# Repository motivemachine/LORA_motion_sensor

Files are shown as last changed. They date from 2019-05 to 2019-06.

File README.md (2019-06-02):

# LoRa Motion sensor
These are the kicad PCB and software files for the LoRa motion sensor, a wireless proximity alarm using the RCWL-0516 sensor and SX1278 radio. PCB designed in Kicad 5.1. The cache should contain all custom footprints. Handheld receiver design coming soon.

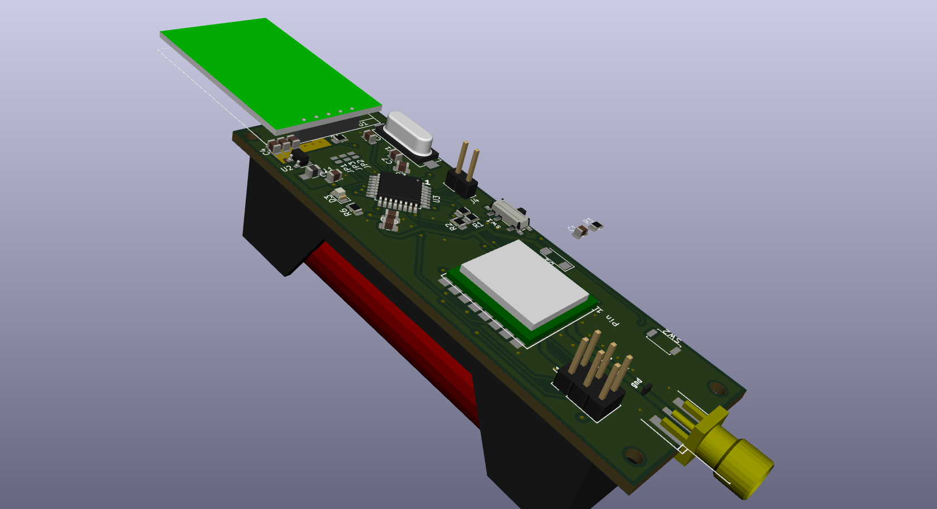
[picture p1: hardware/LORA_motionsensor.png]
sensorrender


### Dependencies
Only dependency is the LoRa radio library by [Sandeep Mistry](https://github.com/sandeepmistry/arduino-LoRa), included in _/firmware/lib/_

### Software usage
Software was created and compiled with PlatformIO, but is usable by any arduino compatible IDE by compiling the program located in _/firmware/src_ as an arduino pro mini 3.3v/8mhz. Upload is done over ISP header. Be careful that programming signals are 3.3 volts, as the LoRa radio is not 5v tolerant.

### Using the device
Simply turn it on and place in an area you'd like to monitor. Choke points are best, such as near a gate, pathway, doorway or vehicle. The sensor works by detecting a phase change in it's 3Ghz oscillator and waking up the processor and radio, then sending the packet 'MOT' via LoRa radio protocol, along with packet and radio ID number.

Sensor range is about 20-30ft out the front and back, and less to the sides. Range seems somewhat dependent on size and speed of the object (dog, man, car, etc.), and whether or not the object is moving across or toward/away from the sensor. Sensor is immune to changes in heat or light, and can 'see' through non-conductive objects. It detects movement of conductive objects, be they people, animal or metal vehicle, and sometimes large amounts of tree leaves. Beware if placing near large leafy things in the wind.

The best documentation on the function and use of this sensor can be found here: (https://github.com/jdesbonnet/RCWL-0516)

The only critical part of placing it is near metal or another sensor. Any metal closer than about 2" to the sensor will cause it to go off constantly, and the sensors will interfere with each other closer than about 10feet(~3meters)

Testing is still ongoing, but the device is mostly feature complete. Sleep modes on the radio and ATmega are getting about two weeks (depending on number of wakeups) on a single 18650 battery.  

### Still todo

- [ ] program CRC and collision detection functions
- [ ] write functions for setting destination and local HEX address with switches or solder jumpers
- [ ] update and test boards with low-battery alert functions
- [x] upload platformio files
- [x] upload .pdf of schematic
- [ ] generate and upload a proper BOM

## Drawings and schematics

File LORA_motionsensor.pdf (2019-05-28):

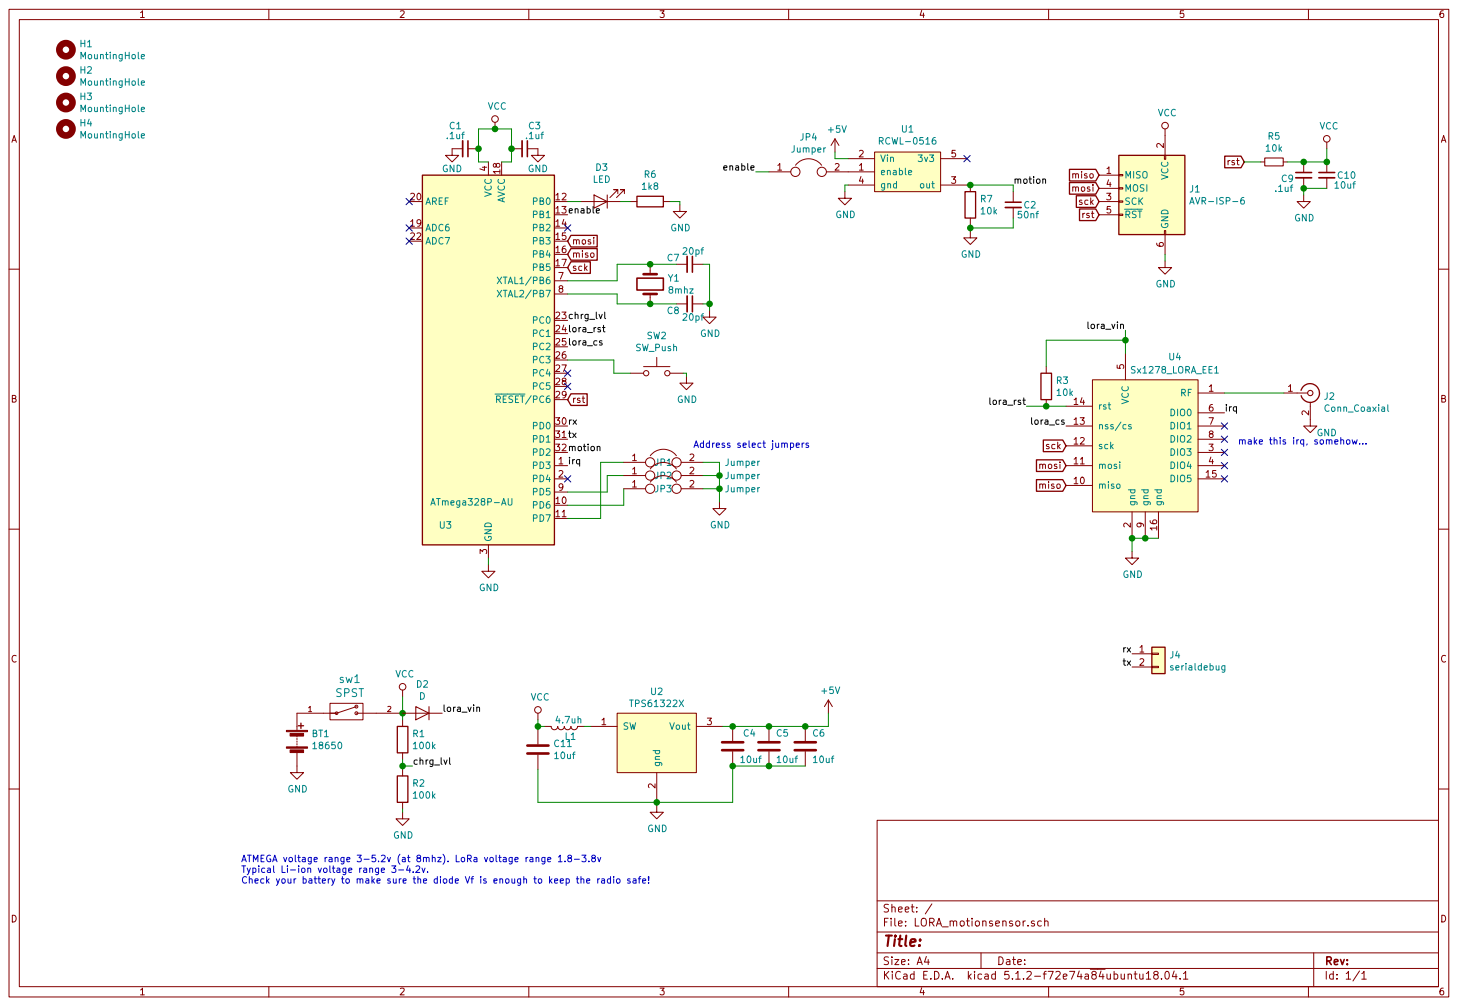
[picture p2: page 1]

2 SCK 3 MOSI 4 RST 5 GND

J2Conn_Coaxial GND miso mosi sck

make this irq, somehow... motion C11

ATMEGA voltage range 3-5.2v (at 8mhz). LoRa voltage range 1.8-3.8v
Typical Li-ion voltage range 3-4.2v.
Check your battery to make sure the diode Vf is enough to keep the radio safe!

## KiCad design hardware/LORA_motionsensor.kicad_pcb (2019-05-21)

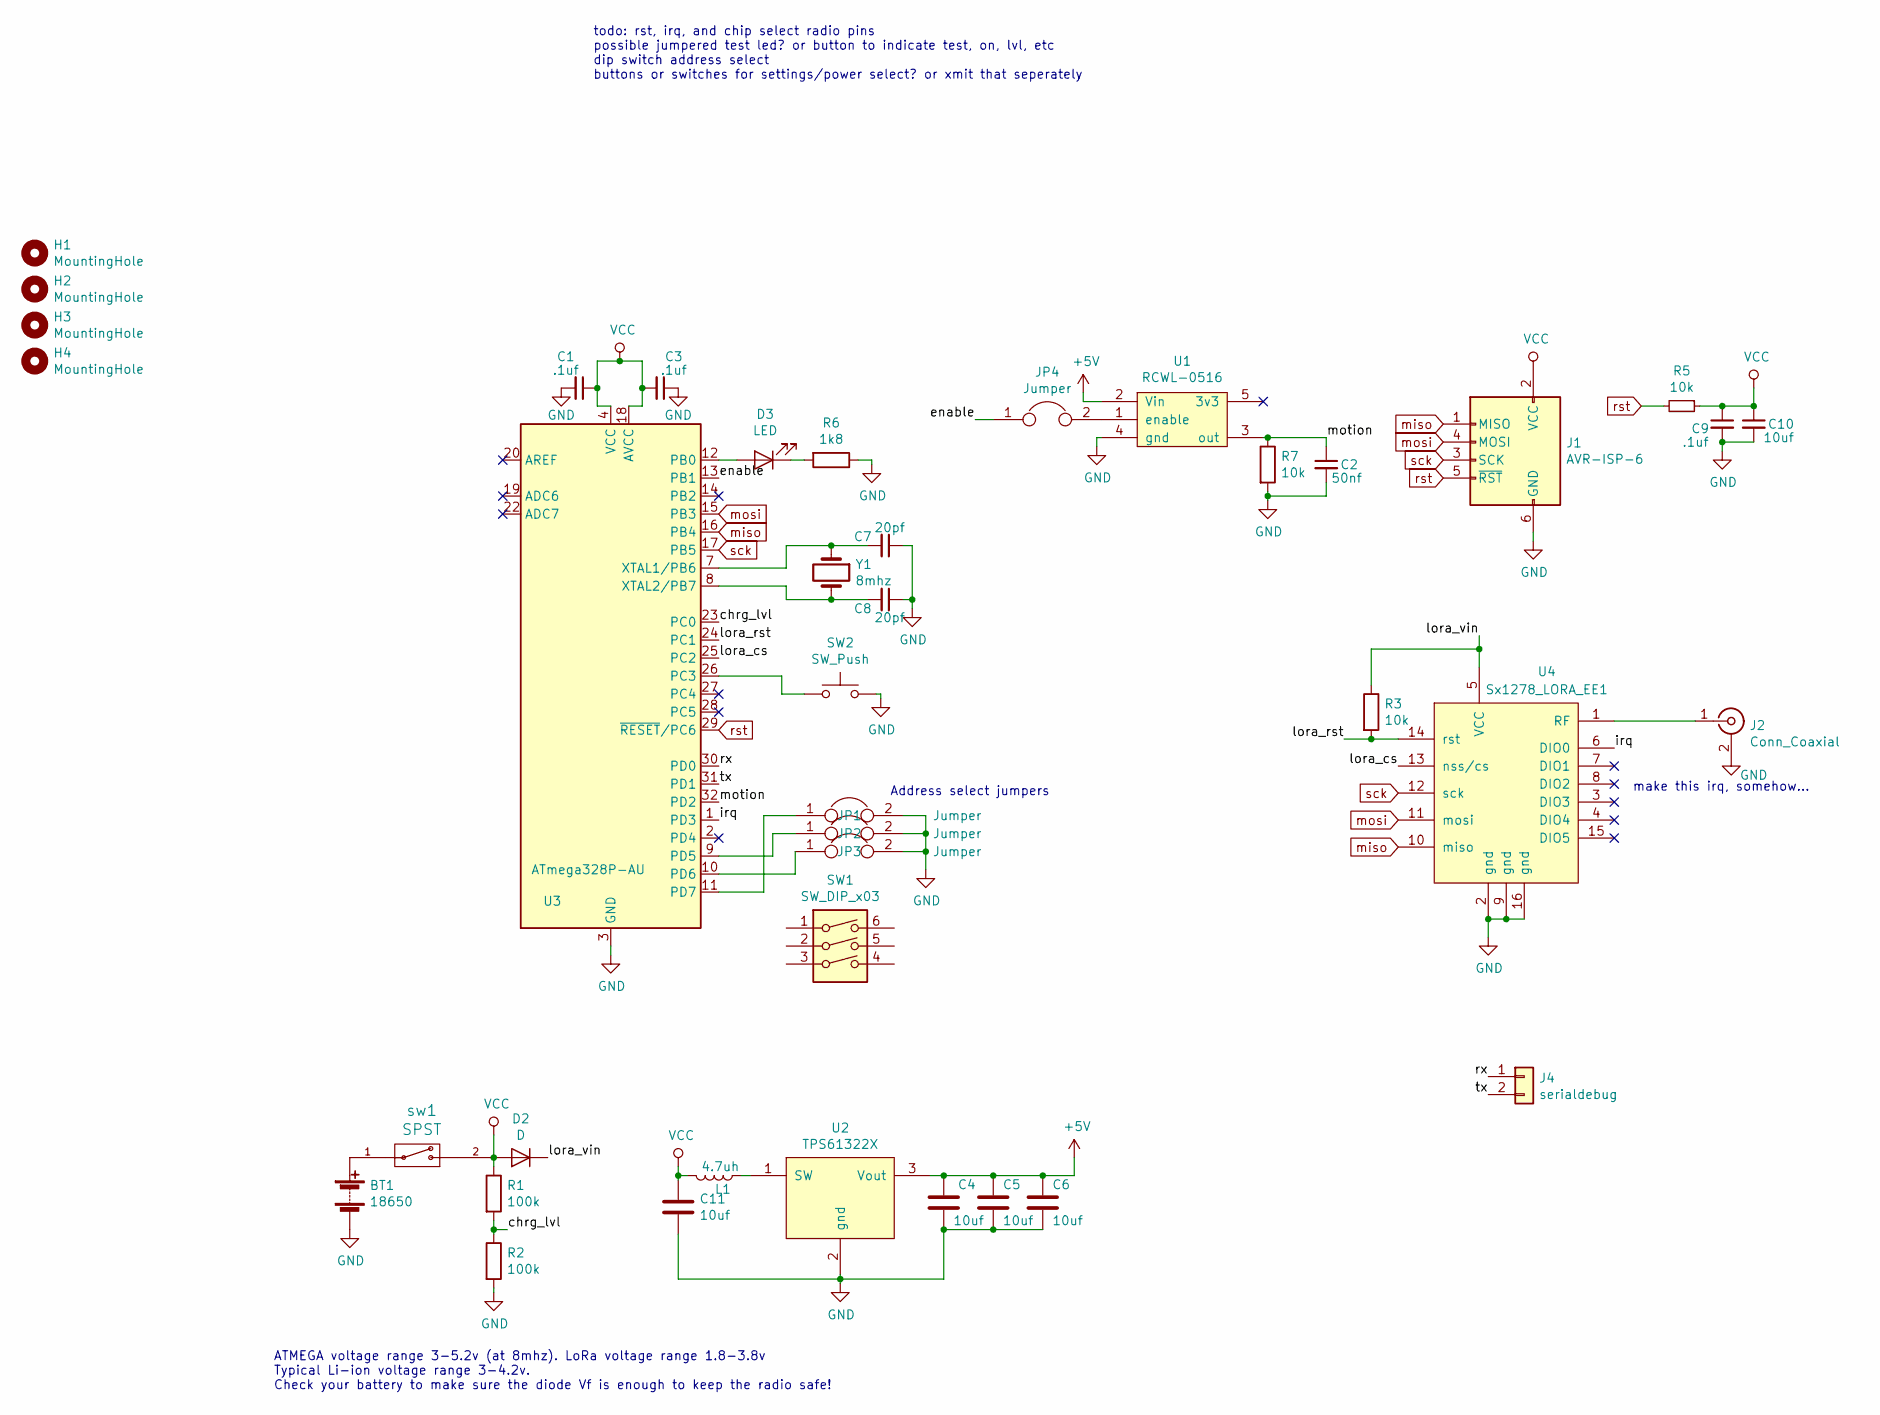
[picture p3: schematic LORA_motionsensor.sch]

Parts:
BT1: 18650; 18650_Single_Holder
C1, C3, C9: .1uf; C_0805_2012Metric
C2: 50nf; C_0805_2012Metric
C4, C5, C6, C10, C11: 10uf; C_0805_2012Metric
C7, C8: 20pf; C_0805_2012Metric
D2: D; D_1806_4516Metric
D3: LED; LED_0805_2012Metric
H1, H2, H3, H4: MountingHole; MountingHole_2.2mm_M2
J1: AVR-ISP-6; PinHeader_2x03_P2.54mm_Vertical
J2: Conn_Coaxial; SMA_edgelaunch_SMD
J4: serialdebug; PinHeader_1x02_P2.54mm_Vertical
JP1, JP2, JP3, JP4: Jumper; solder_jumper
L1: 4.7uh; L_0805_HandSoldering
R1, R2: 100k; R_0805_2012Metric
R3, R5, R7: 10k; R_0805_2012Metric
R6: 1k8; R_0805_2012Metric
SW1: SW_DIP_x03; SW_SPDT_slide_lowprofile
SW2: SW_Push; SW_Push_SPST_NO_Alps_SKRK
U1: RCWL-0516
U2: TPS61322X; SOT-23-5
U3: ATmega328P-AU; TQFP-32_7x7mm_P0.8mm
U4: Sx1278_LORA_EE1; LORA_SX1278_Module
Y1: 8mhz; XTAL_SMD_Standard
sw1: SPST; SW_SPDT_slide_lowprofile

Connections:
+5V: C4.1, C5.1, C6.1, U1.2 (Vin), U2.3 (Vout)
/chrg_lvl: R1.2, R2.1, U3.23 (PC0)
/enable: JP4.1, U3.13 (PB1)
/irq: U3.1 (PD3), U4.6 (DIO0)
/lora_cs: U3.25 (PC2), U4.13 (nss/cs)
/lora_rst: R3.2, U3.24 (PC1), U4.14 (rst)
/lora_vin: D2.1 (K), R3.1, U4.5 (VCC)
/motion: C2.1, R7.1, U1.3 (out), U3.32 (PD2)
/rx: J4.1, U3.30 (PD0)
/tx: J4.2, U3.31 (PD1)
GND: BT1.2 (-), C1.2, C2.2, C3.1, C4.2, C5.2, C6.2, C7.1, C8.1, C9.2, C10.2, C11.2, J1.6 (GND), J2.2 (Ext), JP1.2, JP2.2, JP3.2, R2.2, R6.1, R7.2, SW2.2, U1.4 (gnd), U2.2 (gnd), U3.3 (GND), U3.5 (GND), U3.21 (GND), U4.2 (gnd), U4.9 (gnd), U4.16 (gnd)
unnamed: BT1.1 (+), sw1.1
unnamed: C7.2, U3.7 (XTAL1/PB6), Y1.1
unnamed: C8.2, U3.8 (XTAL2/PB7), Y1.2
unnamed: D3.1 (K), R6.2
unnamed: D3.2 (A), U3.12 (PB0)
unnamed: J2.1 (In), U4.1 (RF)
unnamed: JP1.1, U3.11 (PD7)
unnamed: JP2.1, U3.9 (PD5)
unnamed: JP3.1, U3.10 (PD6)
unnamed: JP4.2, U1.1 (enable)
unnamed: L1.1, U2.1 (SW)
unnamed: SW2.1, U3.26 (PC3)
VCC: C1.1, C3.2, C9.1, C10.1, C11.1, D2.2 (A), J1.2 (VCC), L1.2, R1.1, R5.1, U3.4 (VCC), U3.6 (VCC), U3.18 (AVCC), sw1.2
miso: J1.1 (MISO), U3.16 (PB4), U4.10 (miso)
mosi: J1.4 (MOSI), U3.15 (PB3), U4.11 (mosi)
rst: J1.5 (~RST), R5.2, U3.29 (~RESET~/PC6)
sck: J1.3 (SCK), U3.17 (PB5), U4.12 (sck)

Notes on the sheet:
todo: rst, irq, and chip select radio pins possible jumpered test led? or button to indicate test, on, lvl, etc dip switch address select buttons or switches for settings/power select? or xmit that seperately
make this irq, somehow...
ATMEGA voltage range 3-5.2v (at 8mhz). LoRa voltage range 1.8-3.8v Typical Li-ion voltage range 3-4.2v. Check your battery to make sure the diode Vf is enough to keep the radio safe!
Address select jumpers

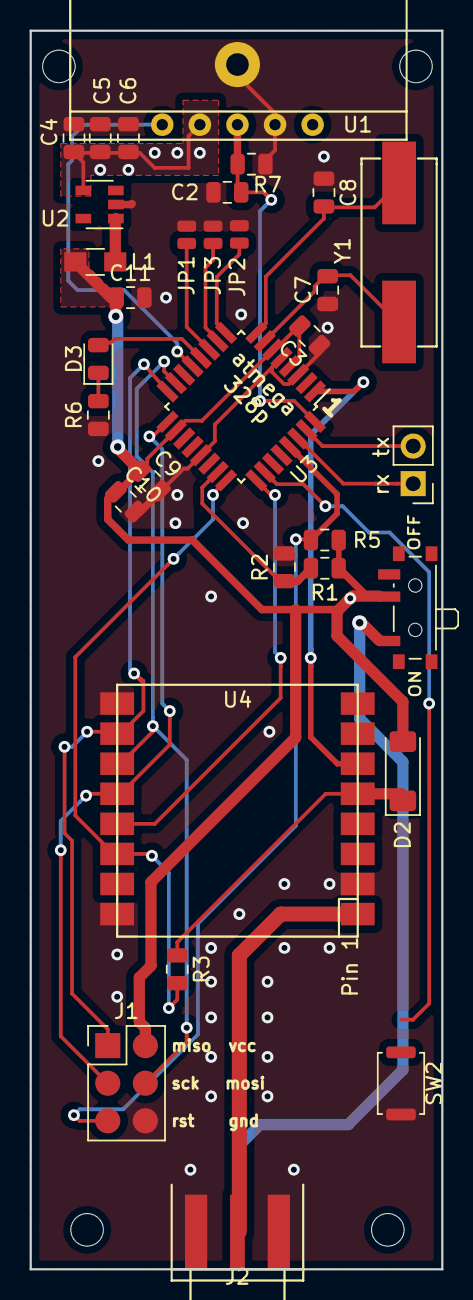
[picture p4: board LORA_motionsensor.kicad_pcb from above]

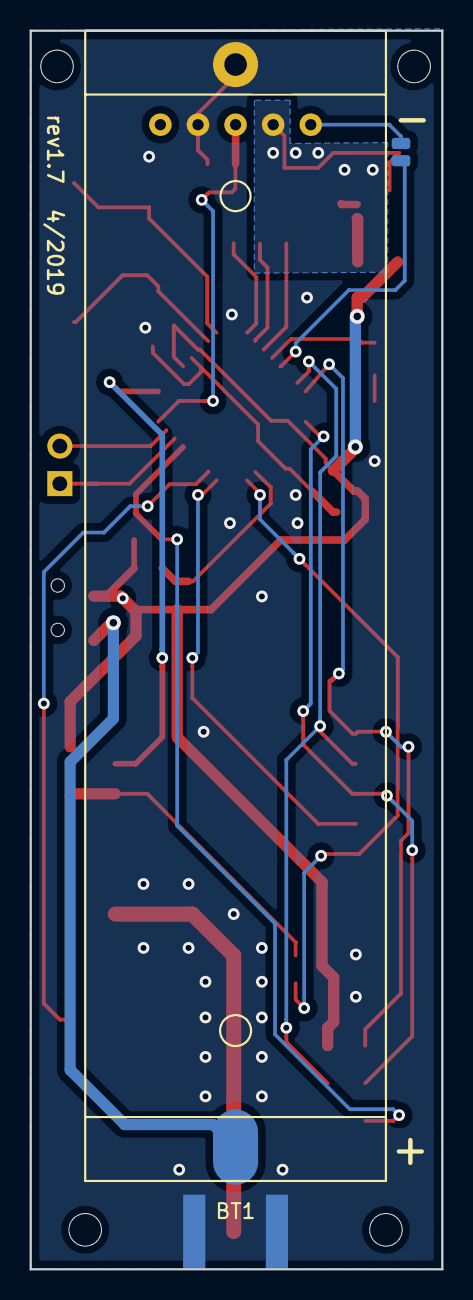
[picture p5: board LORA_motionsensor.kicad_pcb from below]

Board: 2 copper layers, 27.8 x 83.7 mm, 38 parts (2 on the bottom side), 28 nets.

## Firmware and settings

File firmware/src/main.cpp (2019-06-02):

#include <Arduino.h>
#include <avr/interrupt.h>
#include <avr/power.h>
#include <avr/sleep.h>

#include <SPI.h>
#include <LoRa.h>

#define csPin A2
#define resetPin A1
#define irqPin 3 //this is interrupt 1, for the radio receiver

#define led 8
#define button A3

// These are the jumper pins for address selecting
#define jumpone 7
#define jumptwo 5
#define jumpthree 6

int chrg_lvl = A0;

int localAddress;       //the radio address to be set by a function that reads jumpers or dip switches
int motionPin = 2;      // this is interrupt 0, for the motion sensor. It is pulled low by 100k
int wakedelay = 4000;   //stay awake for 4 seconds before re-enabling interrupt and going back to sleep
int counter = 0;
byte destination = 0x25;

String const motAlert = "MOT";

int battVolt; //ADC reading of battery voltage, through a 100k-100k voltage divider
bool battlow = false; // a variable to pass to the motion alert interrupt. It will append a message that the battery is low if it is below 10%

void getaddr()           //read dip switches to determine device address on startup
  {
  //byte jumperArray[3];
  localAddress = 0x28;   //temporarily hard coding this for testing
  }


void errorBlink() //blink the led if the radio hangs. LoRa.endPacket() returns 1 if successful, 0 if error.
{
  for (int i = 0; i<21 ; i++)
  {
    digitalWrite(led, HIGH);
    delay(100);
    digitalWrite(led, LOW);
    delay(100);
  }
}

void wakeUp() // ISR to send message when motion detected
{
  sleep_disable();
  detachInterrupt(digitalPinToInterrupt(motionPin));
}

void motion_alert() //Send the motion detected message.
  {
    // send packet
    LoRa.beginPacket();                   // start packet
    LoRa.write(destination);              // add destination address
    LoRa.write(localAddress);             // add sender address
    LoRa.write(1);                        // add message ID
    LoRa.write(motAlert.length());        // add payload length
    LoRa.print(motAlert);                 // add payload
    if (!LoRa.endPacket())
    {
      errorBlink();
    }
  }

void sleepNow()
  {
   //Serial.println("going to sleep.");
   set_sleep_mode(SLEEP_MODE_PWR_DOWN);   // sleep mode is set here
   noInterrupts();
   sleep_enable();          // enables the sleep bit in the mcucr register so sleep is possible. just a safety pin
   attachInterrupt(digitalPinToInterrupt(motionPin), wakeUp, RISING);
   delay(10);
   interrupts();
   sleep_cpu(); // trying sleep_cpu instead of sleep_mode
   //sleep_mode();            // here the device is actually put to sleep.
  }

void batteryVoltage() // get a read on the battery level, convert to percentage and set batt_low flag if it is below 10%
{
  //Serial.println("Battery Voltage function");
  battVolt = analogRead(chrg_lvl) * 2; //battery level as read through the 100k-100k voltage divider
  //Serial.print("Divider is: "); Serial.println(divider);
  if (battVolt <= 800) {battlow = true;} // Low battery will probably be around 3.1 volts, but we'll set this flag when the battery is just slightly drained for testing purposes
  else {battlow = false;}
}

 void batteryAlert()
{
    String battMessage = "BATT: "  +  (String)battVolt;
    LoRa.beginPacket();                   // start packet
    LoRa.write(destination);              // add destination address
    LoRa.write(localAddress);             // add sender address
    LoRa.write(9);                        // add message ID
    LoRa.write(battMessage.length());     // add payload length
    LoRa.print(battMessage);              // add payload
    if (!LoRa.endPacket())
    {
      errorBlink();
    }                                     // finish packet and send it
}



void setup() {
  LoRa.setPins(csPin, resetPin, irqPin);

  pinMode(chrg_lvl, INPUT);
  pinMode(led, OUTPUT);

  for (int i = 0; i<9; i++) //blink led on startup
  {
    digitalWrite(led, HIGH);
    delay(50);
    digitalWrite(led, LOW);
    delay(50);
  }

  pinMode(jumpone, INPUT_PULLUP);
  pinMode(jumptwo, INPUT_PULLUP);
  pinMode(jumpthree, INPUT_PULLUP);
  getaddr(); //get the address set for the LORA radio

  pinMode(motionPin, INPUT); //has external pulldown resistor

  if (!LoRa.begin(430E6)) {
    errorBlink();
  }
  batteryVoltage(); //temporary to give an idea of battery power on startup
  batteryAlert();
  delay(8000);   //Wait a bit after startup for user to move out of the way

}


void loop() {
  delay(100);
  sleepNow(); // no more motion detected. Going to sleep
  while (digitalRead(motionPin) == HIGH) //after waking up and sending the motion packet, check again for motion. If the sensor pin is still high, don't go back to sleep- send another packet!
  {
    digitalWrite(led, HIGH);            //you can turn on the LED here if you wish for testing the motion sensor.
    motion_alert();
    batteryVoltage();
    batteryAlert();                     // battery alert will only happen when low eventually. Transmit every time for now to get an idea of battery discharge profile.
    delay(wakedelay);
    digitalWrite(led, LOW);
  }
  //batteryvoltage();                  // check battery voltage. if below threshold, send low voltage alert.
  //if (battlow == true){batteryAlert();}
}

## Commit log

2019-05-21 uploading kicad files
    [LORA_motionsensor.kicad_pcb, LORA_motionsensor.sch]
2019-05-28 add .pdf schematic
2019-06-02 added battery test functions
